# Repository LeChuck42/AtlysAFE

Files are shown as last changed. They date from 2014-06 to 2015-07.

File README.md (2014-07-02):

AtlysAFE
========

The goal of this project is an analog frontend for the [Digilent Atlys](http://www.digilentinc.com/Products/Detail.cfm?NavPath=2,400,836&Prod=ATLYS) FPGA Development Board.
The board consists of a XILINX Spartan 6 FPGA and several peripherals. Other expansion modules
can be connected via the VHDCI connector.

The analog frontend will use this expansion port to connect two high speed ADCs and two high speed
DACs to the FPGA. My plan it to use this board as a base for a [Software Defined Radio](http://en.wikipedia.org/wiki/Software-defined_radio).

Layout
------
For most of the ICs free samples are available and the footprints are designed in a way that allows the board to be hand-soldered (using QFN with long pads and no BGA).

I chose a 6 layer layout because the impedance controlled traces need a small distance to their reference plane. In small quantities it seems to be cheaper to use 6 layers instead of defining a low prepreg thickness for a 4 layer design.

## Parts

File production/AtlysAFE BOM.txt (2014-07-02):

Comment	Description	Designator	Footprint	LibRef	Quantity

"0603_MUX4"	""	"R103, R104, R105, R106"	"0603_MUX4"	"0603_MUX4"	"4"
"600R@100Mhz"	""	"L300, L600, L601"	"0805"	"L"	"3"
"93LC56C"	"2K Microwire Compatible Serial EEPROM"	"IC601"	"MSOP8"	"93LC56C"	"1"
"LMK00304"	"3-GHz 4-Output Differential Clock Buffer/Level Translator"	"IC701"	"WQFN32_LONG"	"LMK00304"	"1"
"GPIO"	"16POLPF"	"P3"	"16POL_PF2"	"16POLPF"	"1"
"TPS7A4700"	"36V, 1A, Low Noise, RF LDO Voltage Regulator"	"IC500, IC502"	"VQFN20_LONG"	"TPS7A4700"	"2"
"VHDCI-68"	"68-Pin VHDCI Connector"	"P1"	"VHDCI-68_M"	"MALE_VHDCI-68"	"1"
"USB TYP MICRO-B"	"10118194-0001LF"	"P2"	"USB_MICRO_B_SMD_4DIP"	"USB TYP MICRO-B"	"1"
"120R@100Mhz"	"742792023"	"L500, L502, L503, L504, L506, L507"	"0805"	"L"	"6"
"10.00MHz"	"AST3TQ-10.00MHz-1"	"XO700"	"AST3TQ"	"OSZILLATOR_4P SMD"	"1"
"100n"	"C"	"C101, C102, C103, C104, C106, C107, C108, C110, C111, C114, C115, C120, C155, C200, C201, C204, C208, C209, C212, C300, C301, C302, C303, C304, C305, C306, C307, C308, C309, C310, C311, C312, C313, C314, C315, C316, C317, C318, C400, C401, C402, C403, C404, C405, C406, C407, C408, C409, C410, C501, C507, C516, C523, C601, C602, C603, C605, C606, C607, C608, C610, C612, C615, C747"	"0603 SMALL OUTLINE"	"C"	"64"
"100n"	"C"	"C725, C728, C740, C741, C743, C744, C745, C748"	"0402"	"C"	"8"
"100p"	"C"	"C521"	"0603 SMALL OUTLINE"	"C"	"1"
"10n"	"C"	"C511, C520, C737"	"0603 SMALL OUTLINE"	"C"	"3"
"10n"	"C"	"C702, C703, C704, C706, C707, C712, C713, C714, C716, C719, C720, C726, C727, C729"	"0402"	"C"	"14"
"10u"	"C"	"C202, C211, C733, C734"	"0805 SMALL OUTLINE"	"C"	"4"
"18pF"	"C"	"C613, C614"	"0603 SMALL OUTLINE"	"C"	"2"
"1n"	"C"	"C738, C739"	"0603 SMALL OUTLINE"	"C"	"2"
"1n2"	"C"	"C513"	"0603 SMALL OUTLINE"	"C"	"1"
"1nF / 200V"	"C"	"C1, C5"	"1206"	"C"	"2"
"1u"	"C"	"C100, C105, C500, C504, C510, C519, C525, C600, C604, C700, C705, C708, C709, C710, C711, C715, C717, C718, C721, C722, C723, C724, C730, C731, C732, C735, C742, C749"	"0603 SMALL OUTLINE"	"C"	"28"
"22u"	"C"	"C2, C3, C503, C505, C506, C514, C515, C526"	"1206"	"C"	"8"
"270n"	"C"	"C736"	"0603 SMALL OUTLINE"	"C"	"1"
"2n7"	"C"	"C522"	"0603 SMALL OUTLINE"	"C"	"1"
"2nF"	"C"	"C109"	"0603 SMALL OUTLINE"	"C"	"1"
"2u2"	"C"	"C746"	"0603 SMALL OUTLINE"	"C"	"1"
"47u"	"C"	"C502, C508, C509, C517, C518, C524"	"1206"	"C"	"6"
"4u7F"	"C"	"C609, C611"	"0603 SMALL OUTLINE"	"C"	"2"
"C"	"C"	"C118, C119"	"0603 SMALL OUTLINE"	"C"	"2"
"NU"	"C"	"C512"	"0603 SMALL OUTLINE"	"C"	"1"
"TBD"	"C, R"	"C112, C113, C116, C117, C205, C206, C207, C213, C214, C215, R110, R111, R118, R120, R209, R224, R310, R311, R312, R313, R314, R315, R316, R317, R318, R319, R320, R321"	"0603 SMALL OUTLINE"	"C, R"	"28"
"ADP2114"	"Configurable DC/DC Sync. Buck, Dual 2A / Single 4A"	"IC501"	"LFCSP32_LONG"	"ADP2114"	"1"
"4u7"	"DR74-XXX-R"	"L501, L505"	"DR74"	"L"	"2"
"FT2232HL"	"DUAL HIGH SPEED USB TO MULTIPURPOSE UART/FIFO IC"	"IC600"	"64QFN"	"FT2232HL"	"1"
"DAC3283"	"Dual-Channel,  16-Bit,  800  MSPS,  Digital-to-Analog  Converter  (DAC)"	"IC300"	"VQFN48_LONG"	"DAC3283"	"1"
"ADS6245"	"DUAL CHANNEL, 14-BIT, 125/105/80/65 MSPS ADC WITH SERIAL LVDS OUTPUTS"	"IC100"	"VQFN48_LONG"	"ADS6245_2WIRE"	"1"
"100µ"	"EEH-ZA1E101XP"	"C4, C701"	"SMD_ELKO_6.3"	"ELCO"	"2"
"CDCE62005"	"Five/Ten Output Clock Generator/Jitter Cleaner With Integrated Dual VCOs"	"IC700"	"48VQFN"	"CDCE62005"	"1"
"120R"	"L"	"FB700, FB703, FB704, FB705, FB706, FB707, FB709, FB710, FB711"	"0805 SMALL OUTLINE"	"L"	"9"
"1k"	"L"	"FB701, FB702, FB708"	"0805 SMALL OUTLINE"	"L"	"3"
"Ferrite"	"L"	"L700"	"0805"	"L"	"1"
"LCMXO2-2000HC-4TG100C"	"Lattice MachXO2"	"IC400"	"TQFP100"	"LCMXO2-2000HC-4TG100C"	"1"
"MCX"	"MCX Connector"	"X1, X2, X3, X4, X5, X6, X7, X8, X9, X10, X11, X12, X13, X14"	"MCX_TH"	"MCX"	"14"
"(0R)"	"R"	"R207, R222, R717, R719, R726"	"0603 SMALL OUTLINE"	"R"	"5"
"(0R)"	"R"	"R706, R707, R708, R714"	"0402"	"R"	"4"
"(100R)"	"R"	"R720, R725"	"0402"	"R"	"2"
"(500)"	"R"	"R202, R213, R217, R228"	"0603 SMALL OUTLINE"	"R"	"4"
"(50R)"	"R"	"R709, R729"	"0402"	"R"	"2"
"0R"	"R"	"R107, R201, R203, R216, R218, R300, R301, R500, R600, R601, R602, R603, R700, R716, R718"	"0603 SMALL OUTLINE"	"R"	"15"
"0R"	"R"	"R2"	"1206"	"R"	"1"
"0R"	"R"	"R407, R408, R710, R711, R712, R713, R715, R722, R724, R727, R728"	"0402"	"R"	"11"
"100k"	"R"	"R505"	"0603 SMALL OUTLINE"	"R"	"1"
"100R"	"R"	"R303, R306"	"0603 SMALL OUTLINE"	"R"	"2"
"100R"	"R"	"R400, R401, R402"	"0402"	"R"	"3"
"10k"	"R"	"R309, R608, R609, R610, R611, R704, R705"	"0603 SMALL OUTLINE"	"R"	"7"
"10R"	"R"	"R501"	"0603 SMALL OUTLINE"	"R"	"1"
"11k5"	"R"	"R511"	"0603 SMALL OUTLINE"	"R"	"1"
"12k"	"R"	"R612"	"0603 SMALL OUTLINE"	"R"	"1"
"150R"	"R"	"R304, R305, R307, R308"	"0603 SMALL OUTLINE"	"R"	"4"
"15k"	"R"	"R510"	"0603 SMALL OUTLINE"	"R"	"1"
"169R"	"R"	"R204, R208, R219, R223"	"0603 SMALL OUTLINE"	"R"	"4"
"1k"	"R"	"R604, R701, R721, R730"	"0603 SMALL OUTLINE"	"R"	"4"
"1k1"	"R"	"R703"	"0603 SMALL OUTLINE"	"R"	"1"
"1M"	"R"	"R1"	"1206"	"R"	"1"
"220R"	"R"	"R605, R606"	"0603 SMALL OUTLINE"	"R"	"2"
"22k"	"R"	"R101, R508"	"0603 SMALL OUTLINE"	"R"	"2"
"2k2"	"R"	"R613"	"0603 SMALL OUTLINE"	"R"	"1"
"330R"	"R"	"R702"	"0603 SMALL OUTLINE"	"R"	"1"
"33k"	"R"	"R100, R102"	"0603 SMALL OUTLINE"	"R"	"2"
"348R"	"R"	"R200, R214, R215, R229"	"0603 SMALL OUTLINE"	"R"	"4"
"470R"	"R"	"R403, R404, R405, R406"	"0603 SMALL OUTLINE"	"R"	"4"
"47k"	"R"	"R108, R109, R212, R227, R506, R507, R509"	"0603 SMALL OUTLINE"	"R"	"7"
"49R9"	"R"	"R210, R211, R225, R226"	"0603 SMALL OUTLINE"	"R"	"4"
"4k7"	"R"	"R503, R607"	"0603 SMALL OUTLINE"	"R"	"2"
"50R"	"R"	"R112, R113, R114, R115"	"0603 SMALL OUTLINE"	"R"	"4"
"56k"	"R"	"R504"	"0603 SMALL OUTLINE"	"R"	"1"
"5R"	"R"	"R116, R117, R119, R121"	"0603 SMALL OUTLINE"	"R"	"4"
"8k2"	"R"	"R502"	"0603 SMALL OUTLINE"	"R"	"1"
"960R"	"R"	"R302"	"0603 SMALL OUTLINE"	"R"	"1"
"DNP"	"R"	"R723"	"0603 SMALL OUTLINE"	"R"	"1"
"R"	"R"	"R122, R123, R124, R125"	"0603 SMALL OUTLINE"	"R"	"4"
"SMD_MARKER"	"SMD MARKER"	"M1, M2, M3"	"SMDMark100 - nopaste"	"SMD_MARKER"	"3"
"2PPHOE"	"Steckbare Scharubklemme 2pol."	"P4"	"2PPHOE"	"2PPHOE"	"1"
"TEST PAD"	"Test Pad"	"TP500"	"TEST_PAD_50"	"TEST PAD"	"1"
"TESTPOINT"	"TESTPOINT"	"TP700"	"TEST_PAD_50"	"TESTPOINT"	"1"
"THS4509"	"WIDEBAND, LOW-NOISE, LOW-DISTORTION, FULLY-DIFFERENTIAL AMPLIFIER"	"IC200, IC201"	"QFN16_LONG"	"THS4509"	"2"
"RED"	"WURTH 150060SS75000"	"D403"	"LED SMD 0603"	"LED SMD"	"1"
"GRN"	"WURTH 150060VS75000"	"D400, D401, D402, D700"	"LED SMD 0603"	"LED SMD"	"4"
"RX LED"	"WURTH 150060VS75000"	"D600"	"LED SMD 0603"	"LED SMD"	"1"
"TX LED"	"WURTH 150060VS75000"	"D601"	"LED SMD 0603"	"LED SMD"	"1"
"12MHz"	"XX MHz"	"Q600"	"SMD_XTAL_5x3.2"	"CRYSTAL"	"1"
"TBD"	"XX MHz"	"Q700"	"XTAL_SMD_60_35"	"CRYSTAL"	"1"

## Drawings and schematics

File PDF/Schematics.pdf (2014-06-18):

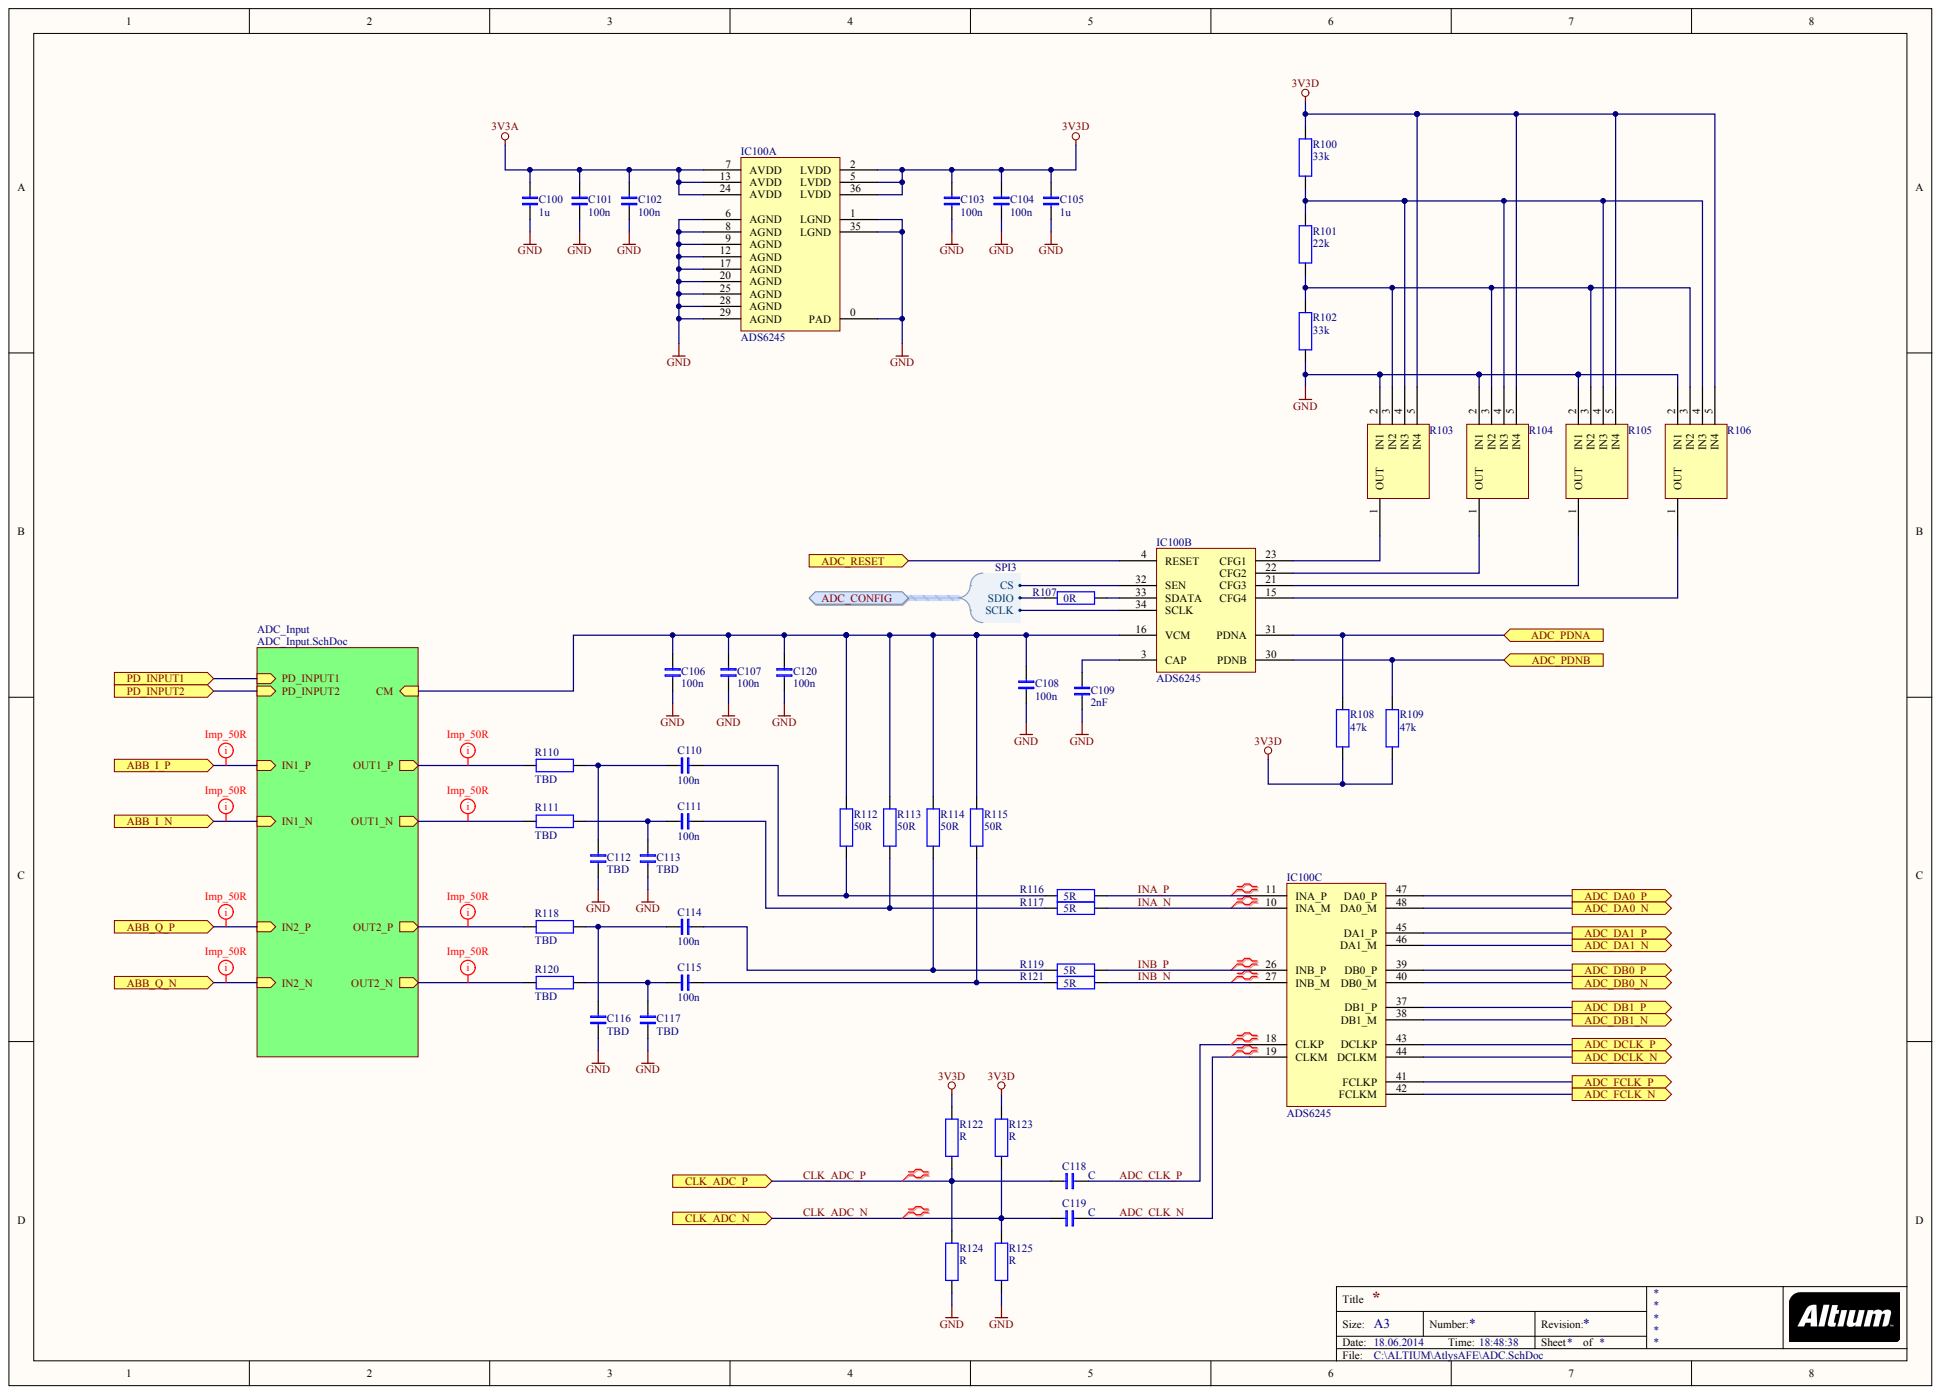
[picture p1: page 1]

AGND 9
AGND 12
AGND 17
AGND 20
AGND 25

AGND 29

Title | *

Size: A3 | Number: | Revision:
Date: 18.06.2014 Time: 18:48:38 | | Sheet * of *

C:\ALTIUM\AtlysAFE\ADC.SchDoc

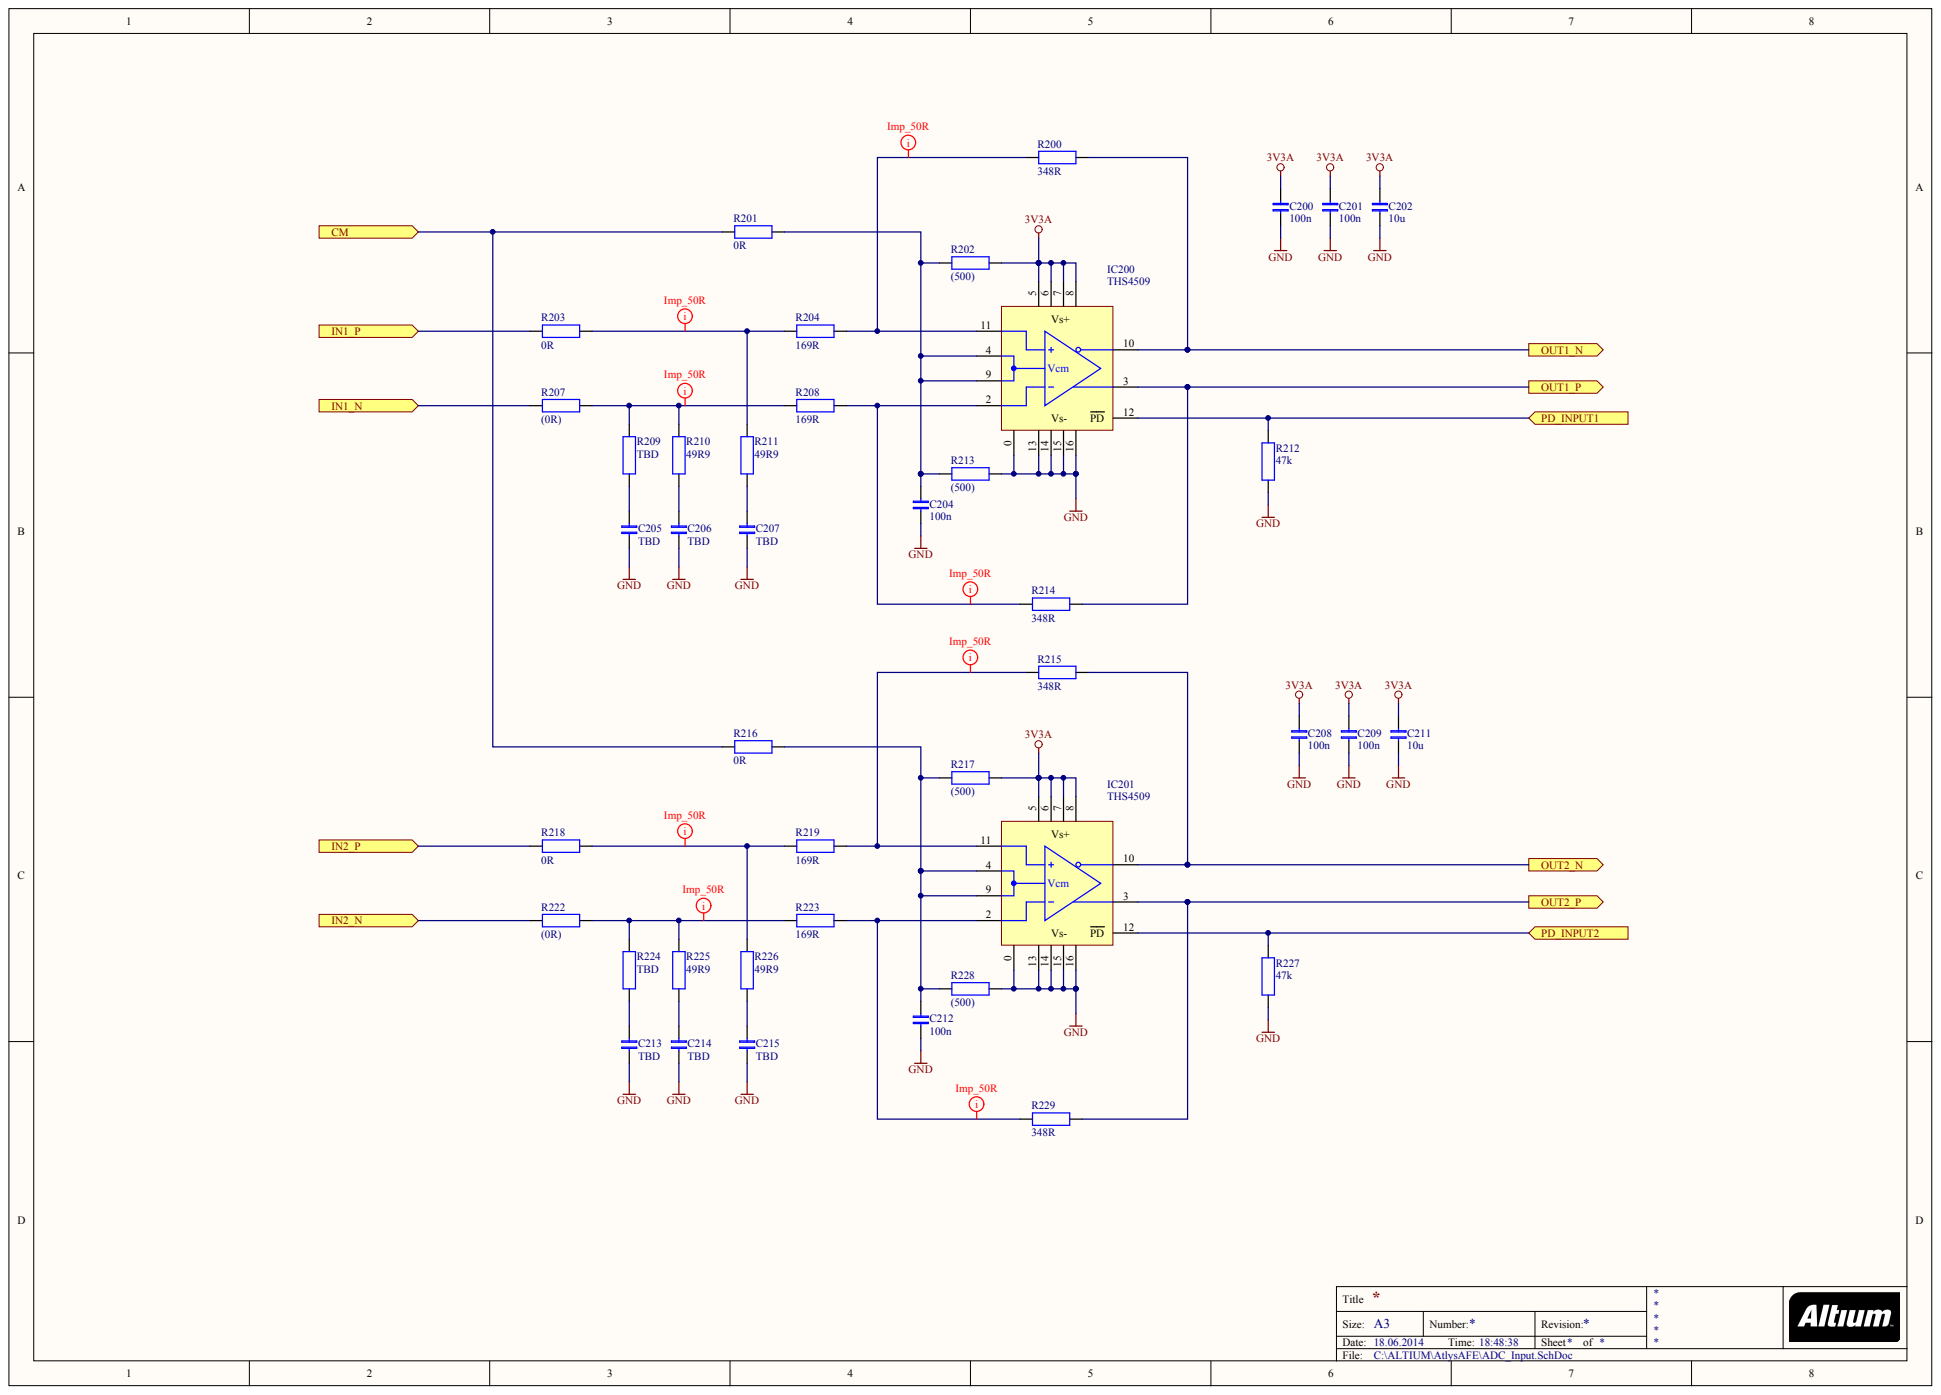
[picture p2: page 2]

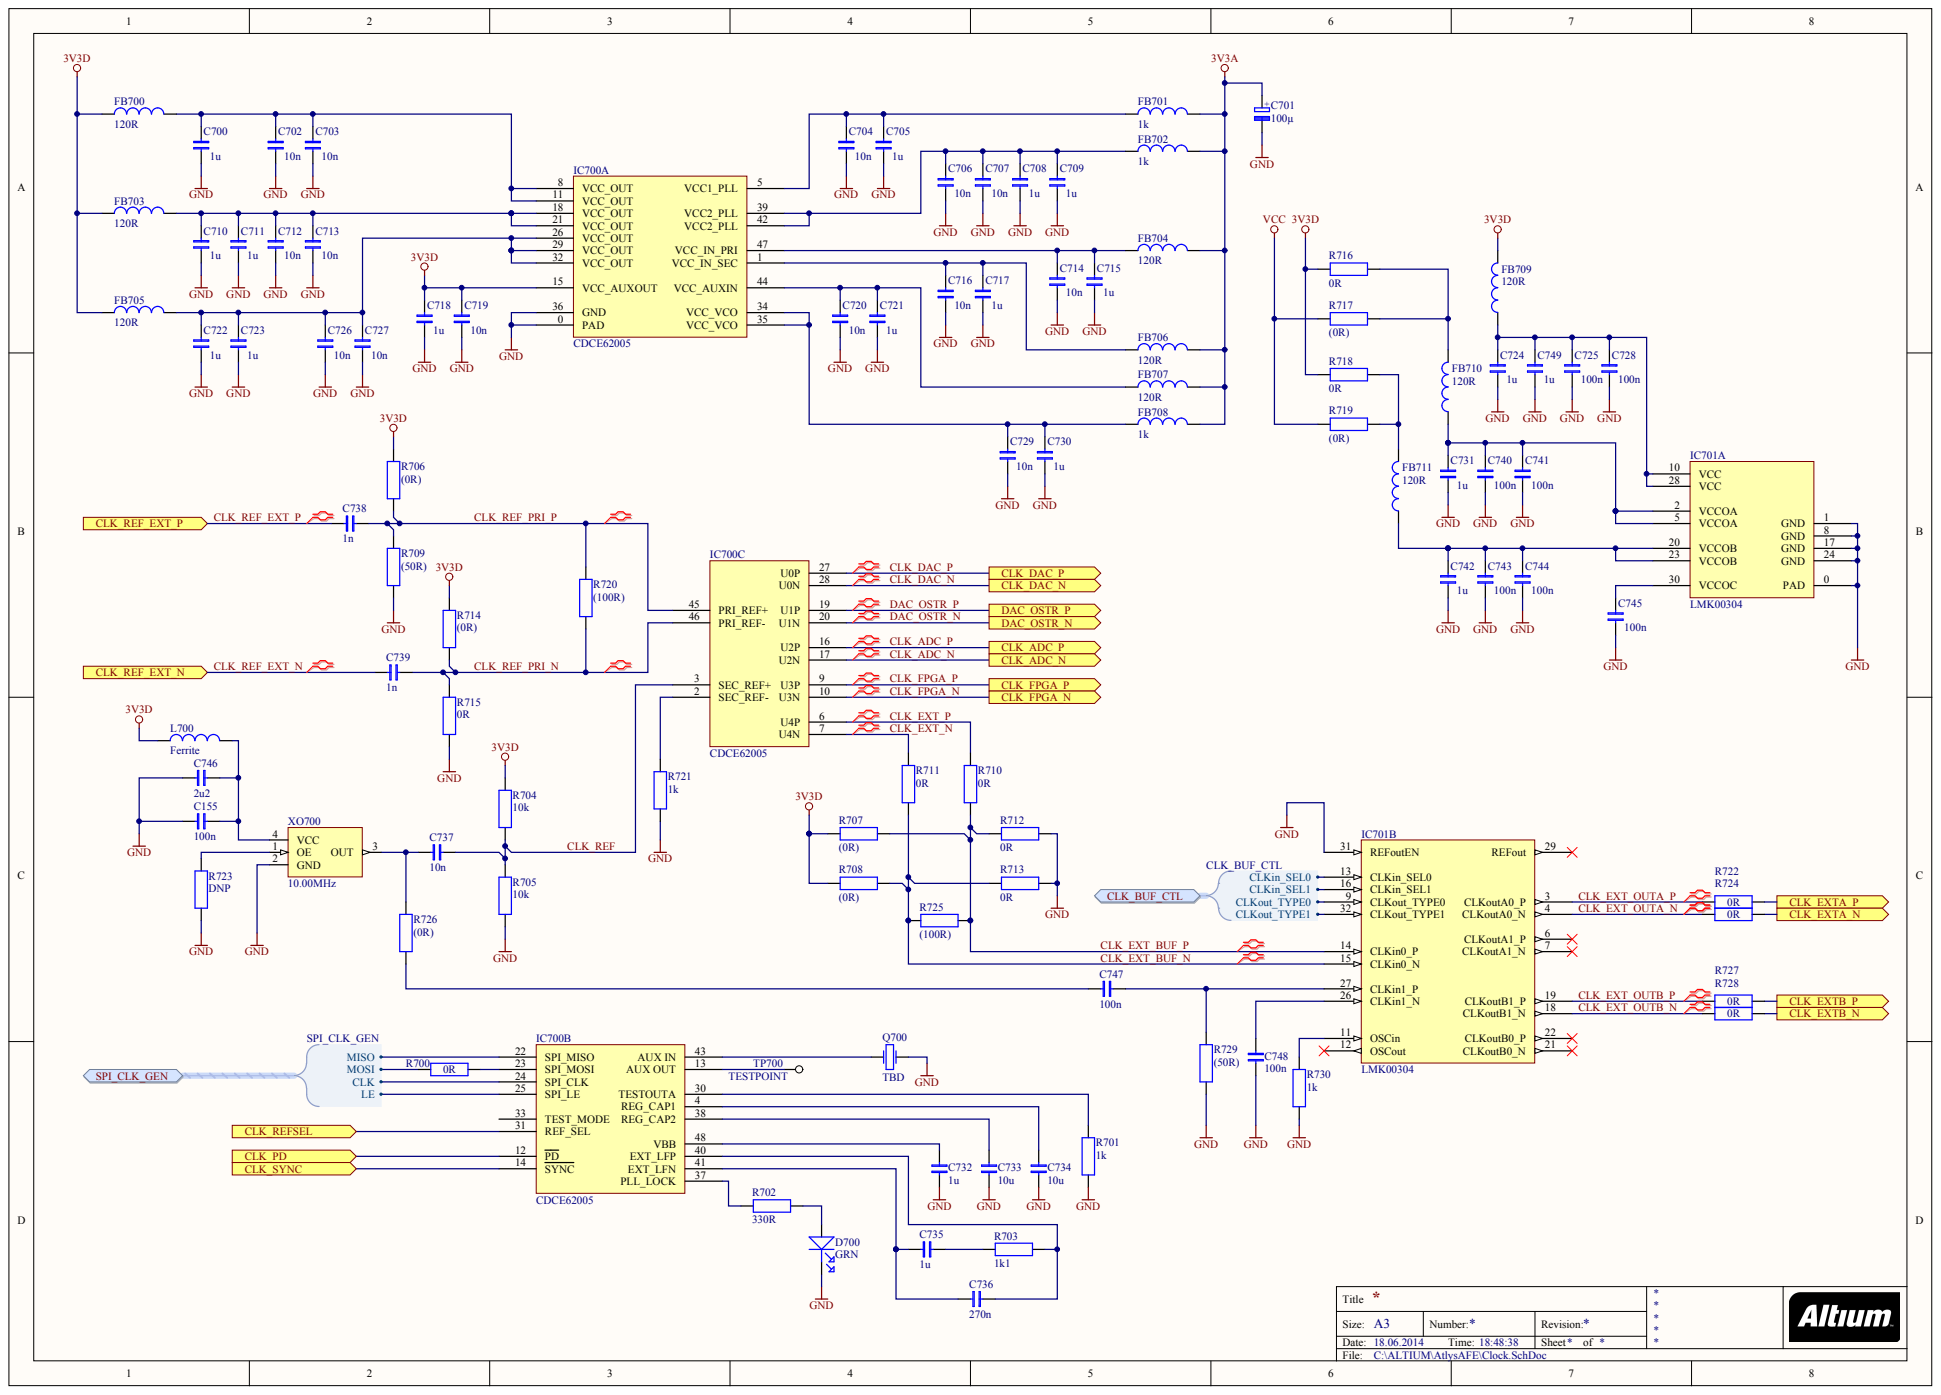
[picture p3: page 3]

PAD 0

GND | GND

CLKin1_N 26 CLKin1_P 27

C:\ALTIUM\AtlysAFE\Clock.SchDoc

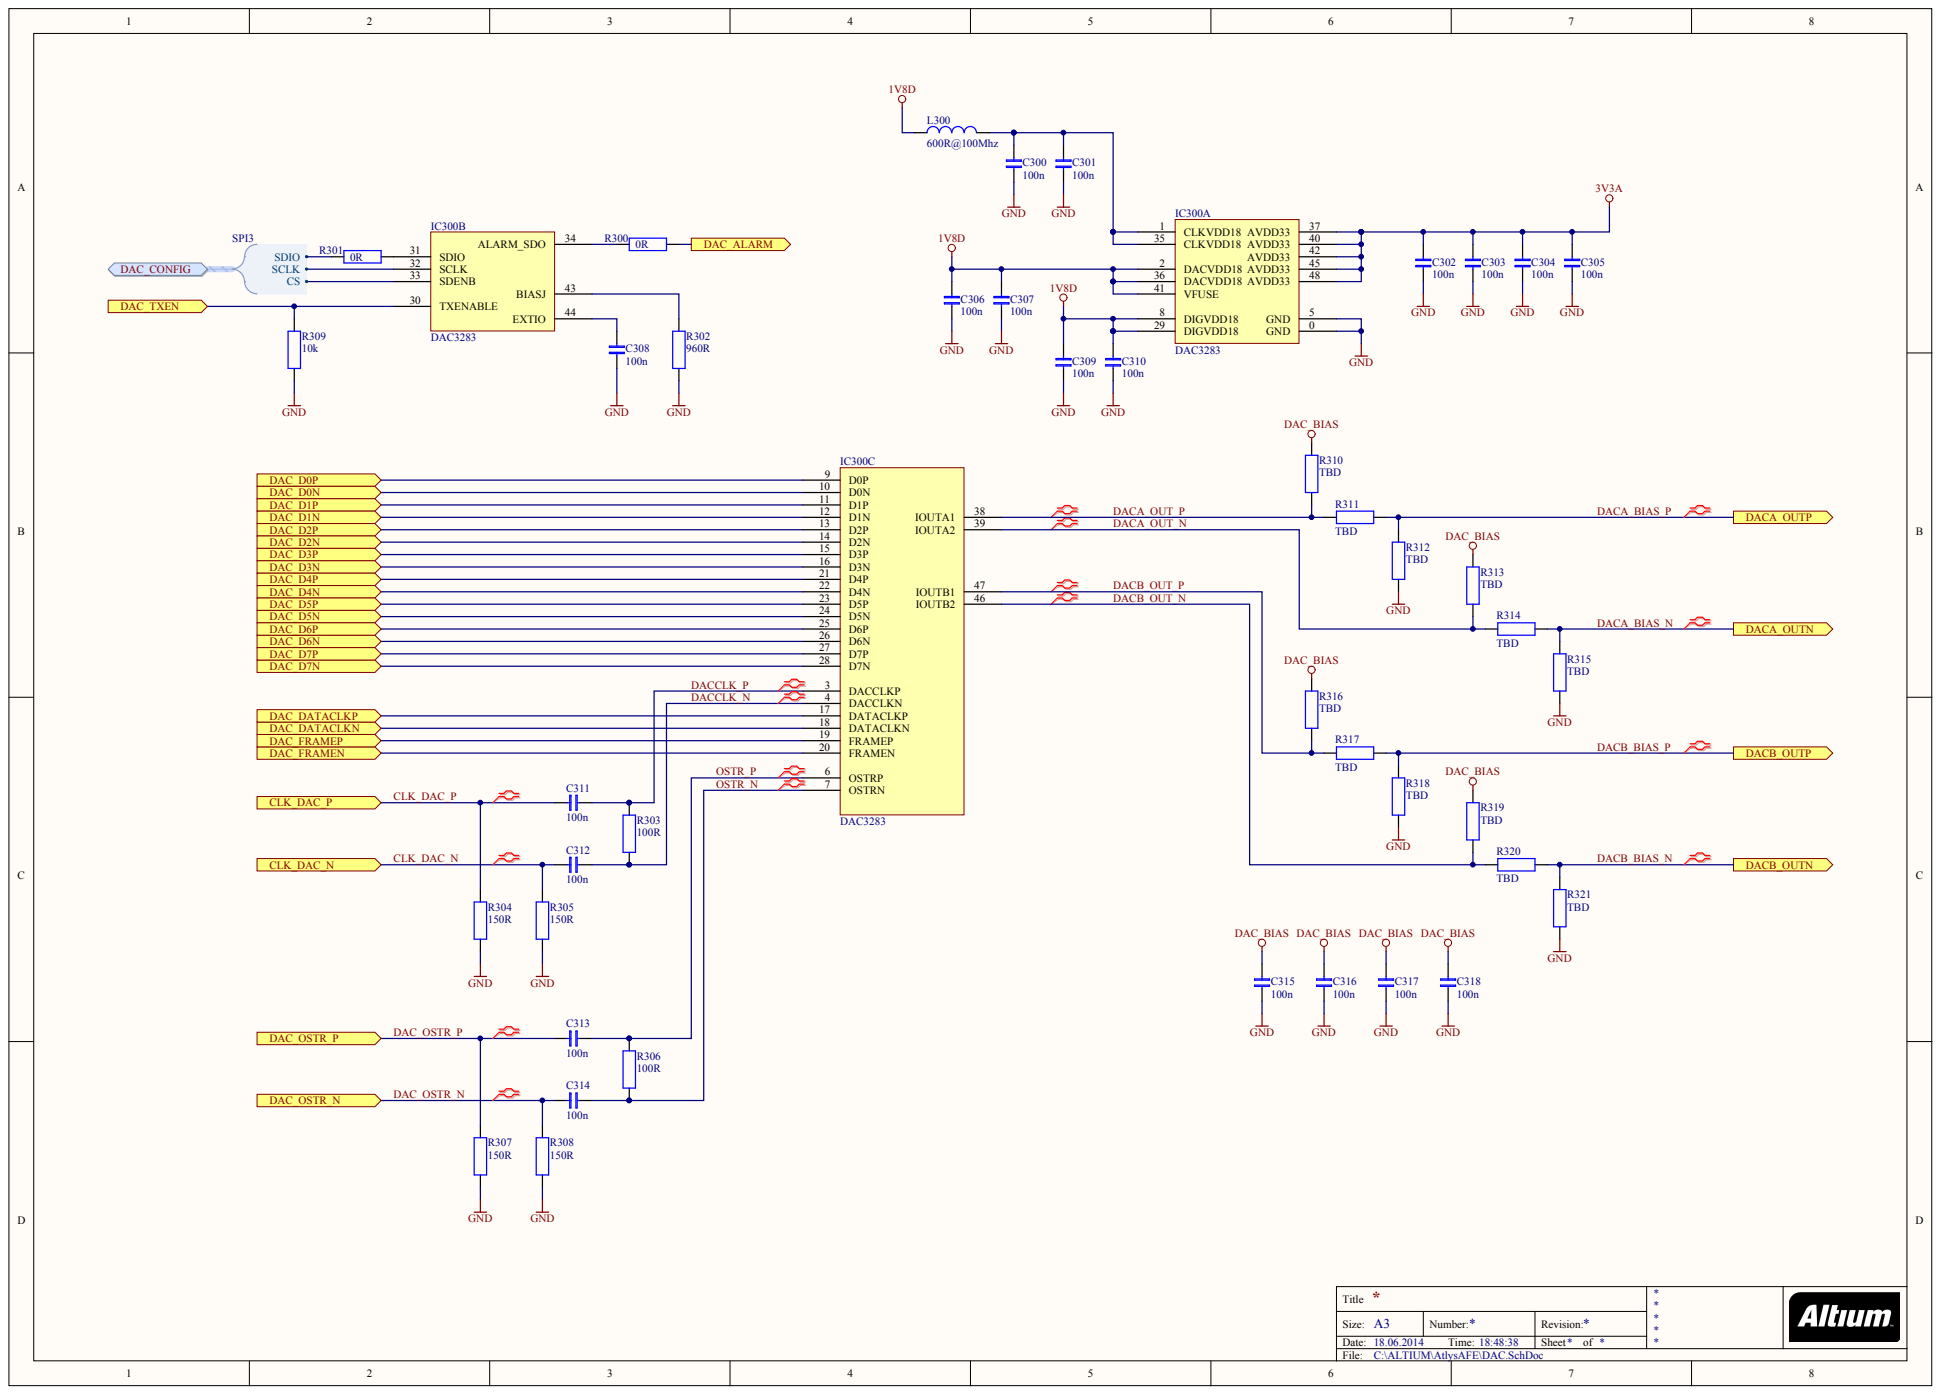
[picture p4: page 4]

D5P 23 | DACB_OUT_N
D5N 24 | | GND

D6N 26 | DAC_BIAS | R317

DACCLK_N | DACCLKN 4

DATACLKP 17
DATACLKN 18
FRAMEP 19
FRAMEN 20

OSTR_P | OSTRP 6
OSTR_N | OSTRN 7

C:\ALTIUM\AtlysAFE\DAC.SchDoc

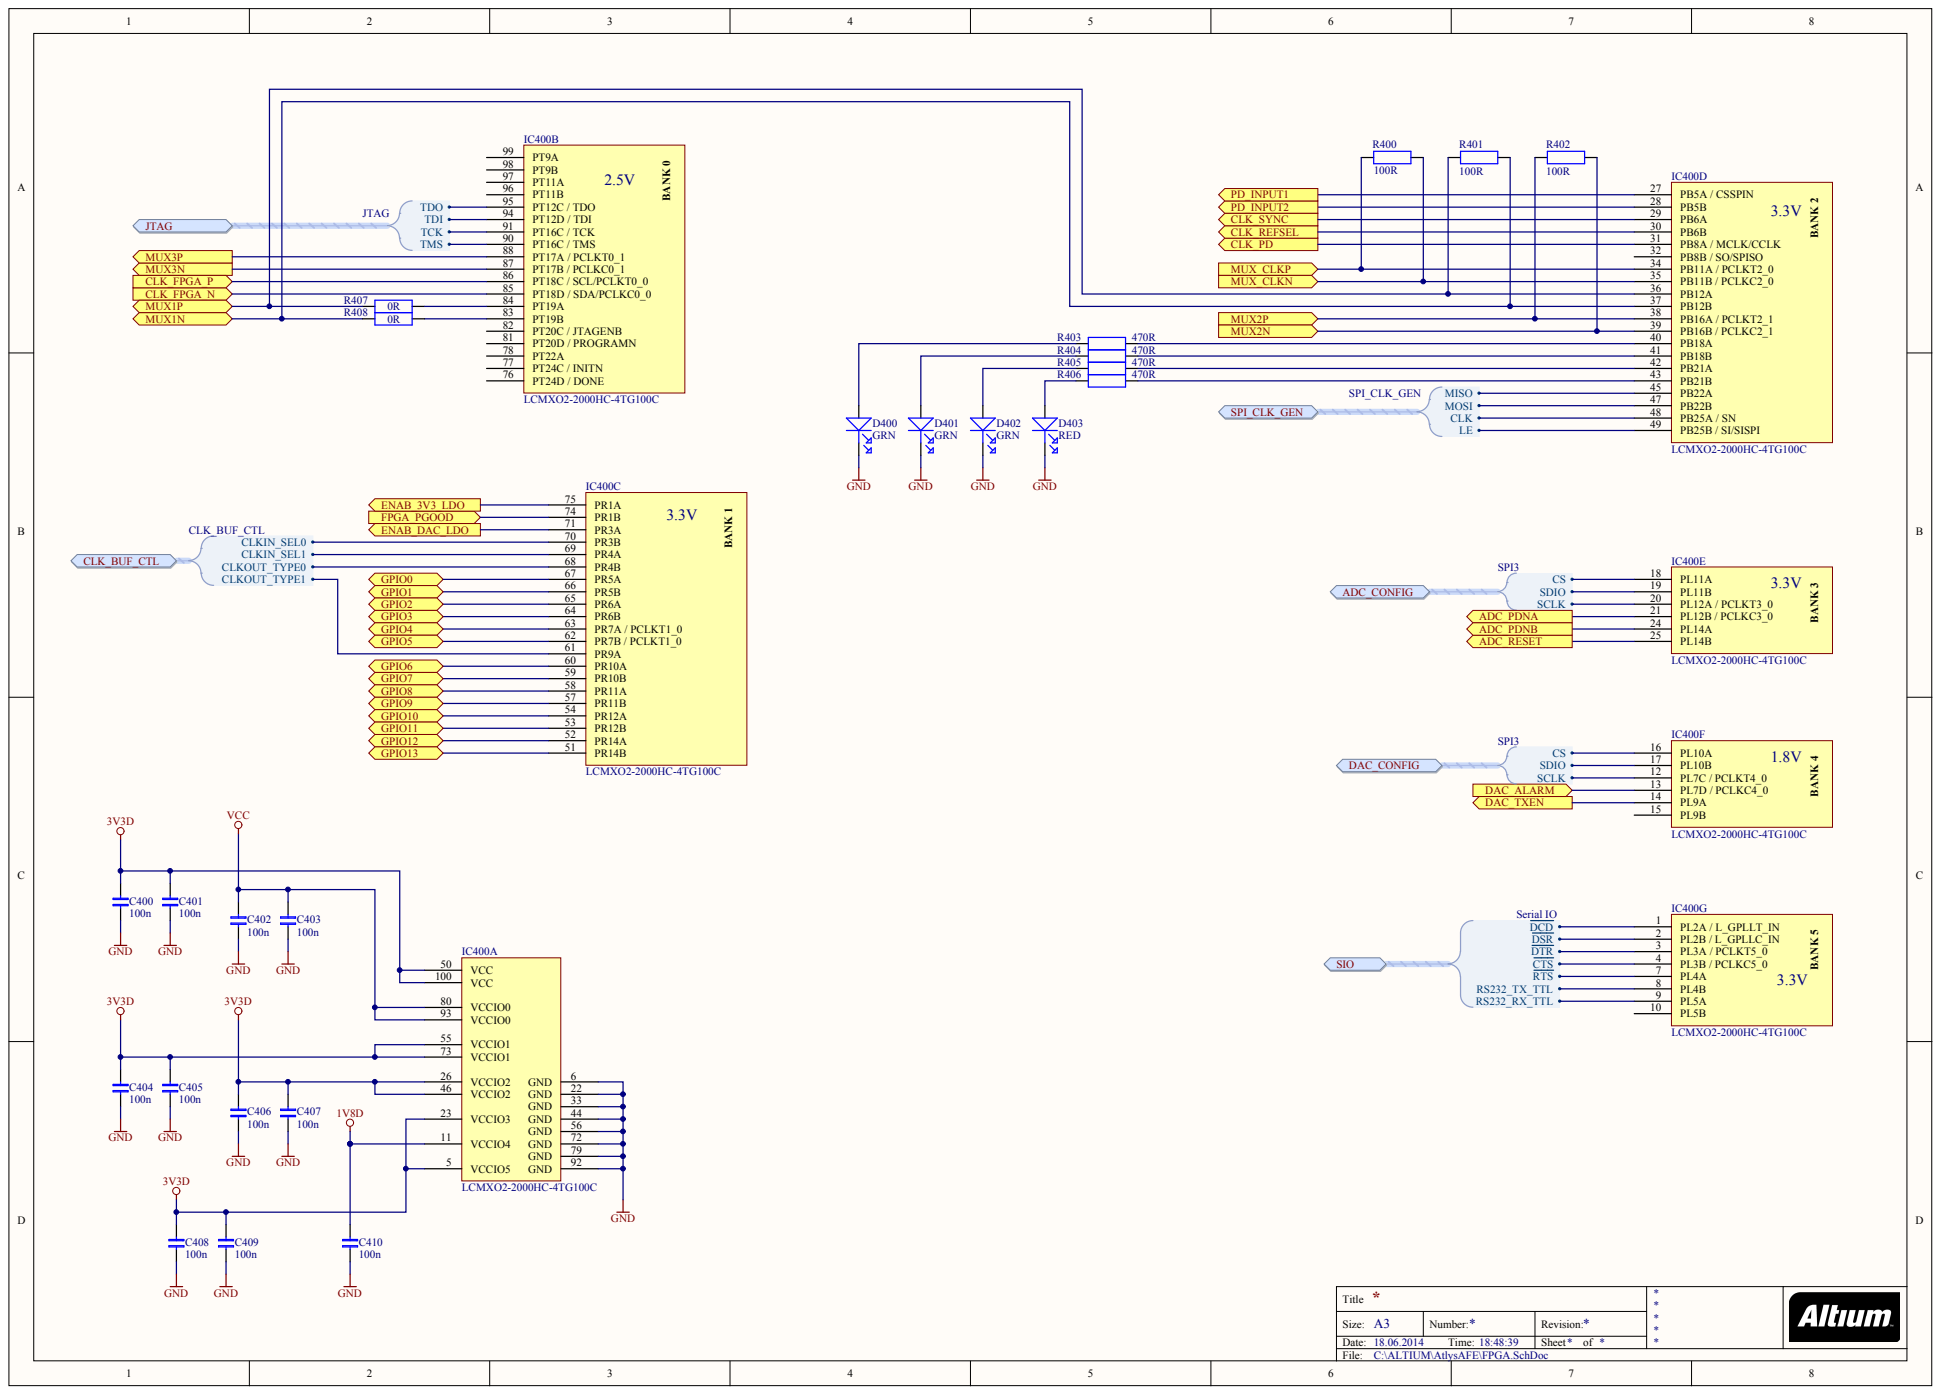
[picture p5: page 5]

R404 | 470R | PB18B 41
R405 | 470R | PB21A 42
R406 | 470R | PB21B 43

C400 GND | C401

C402 GND | C403

VCCIO0 80

C:\ALTIUM\AtlysAFE\FPGA.SchDoc

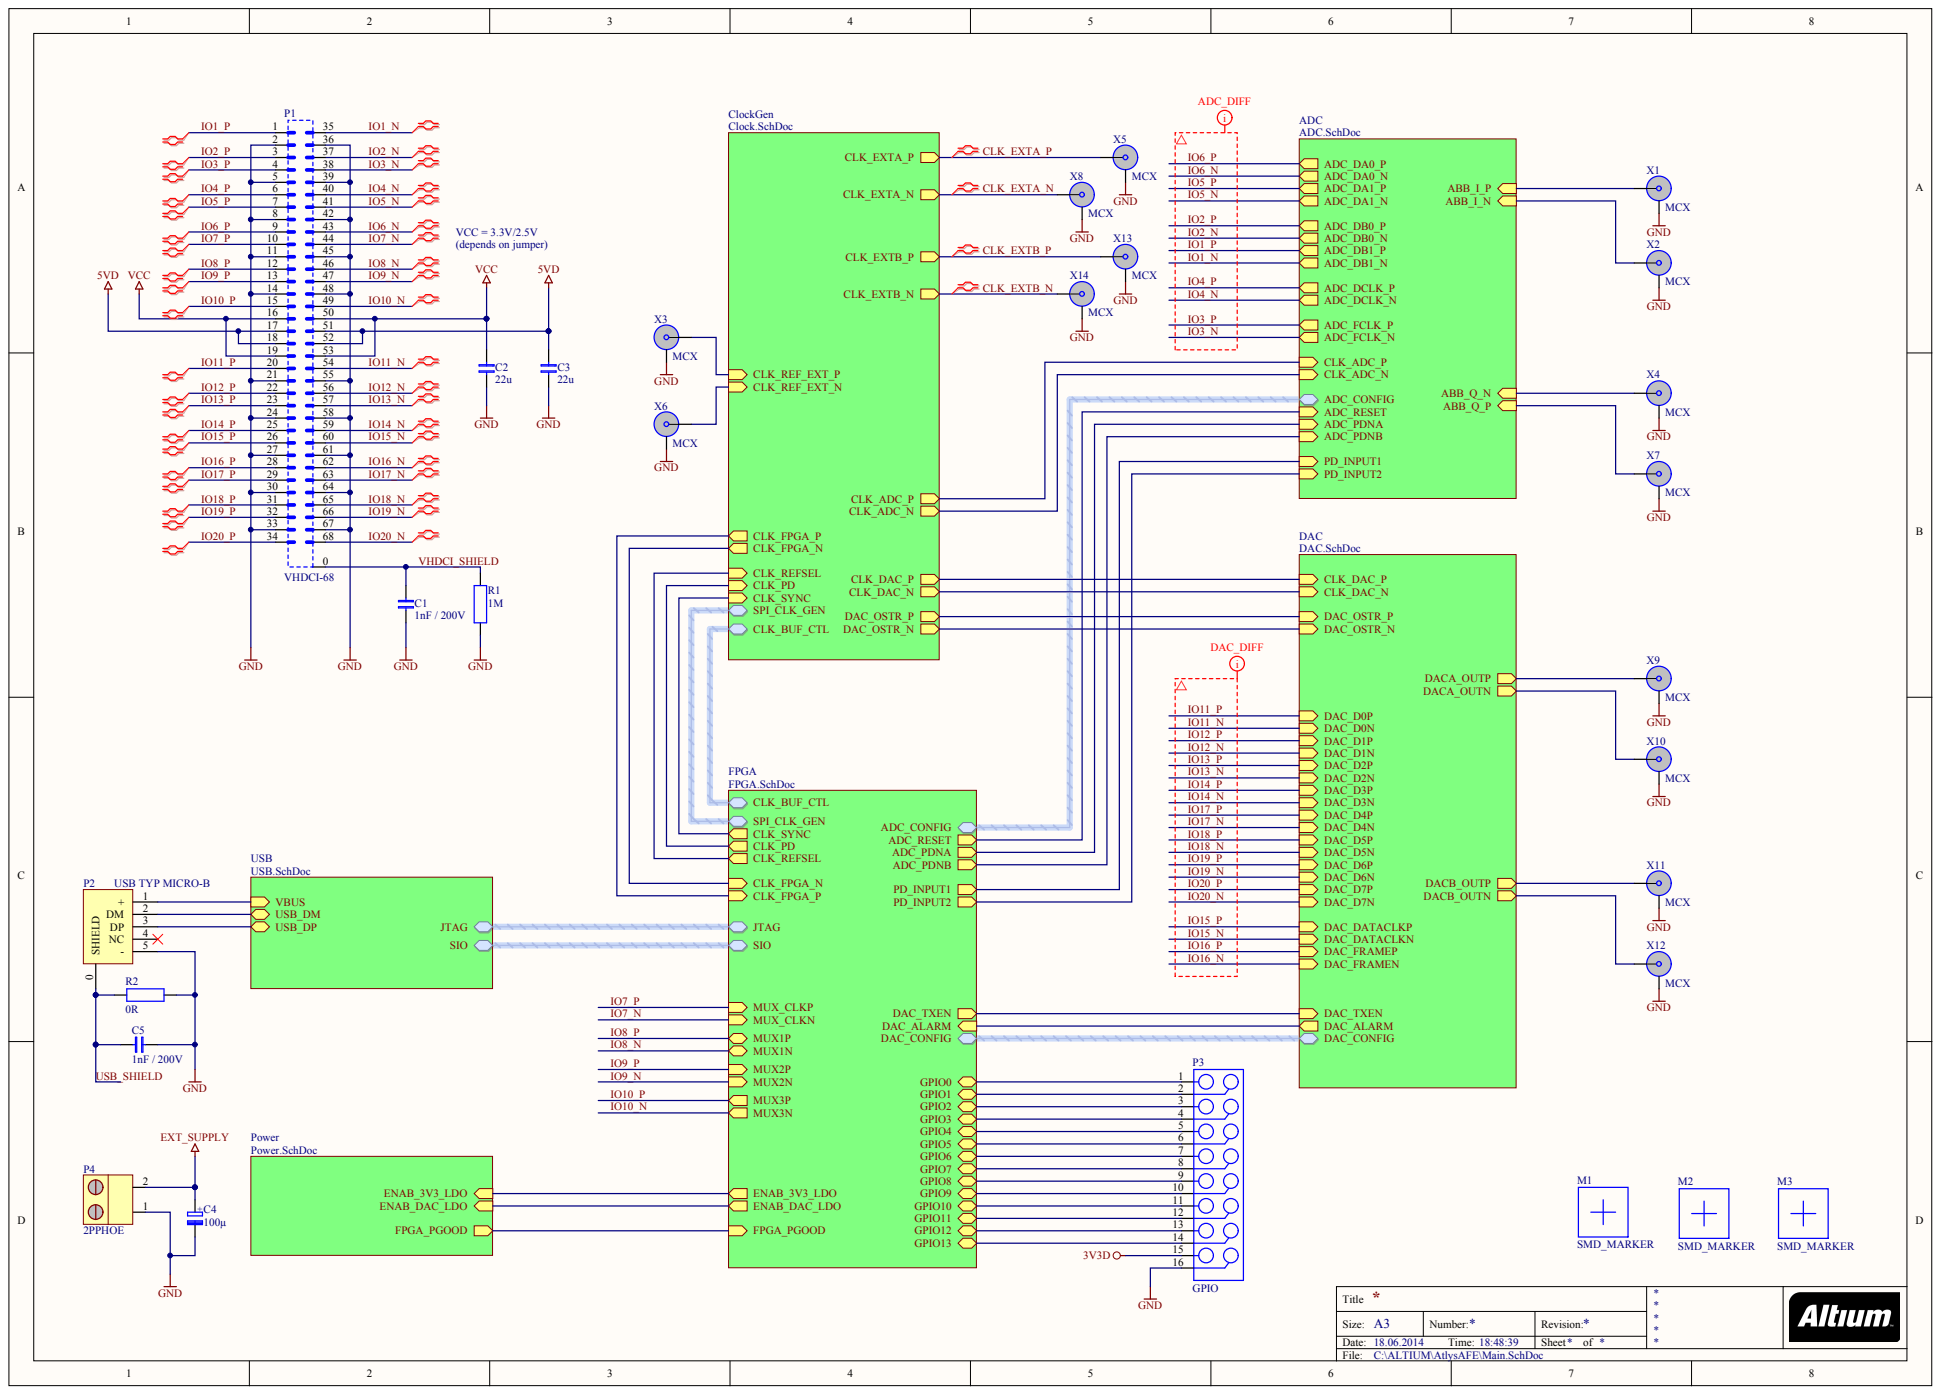
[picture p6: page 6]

17 | | | 51
18 | | | 52 | IO17_N IO18_N IO19_N
19 | | | 53
20 21 | | | 54 55

IO18_N
IO19_P
IO19_N IO20_P

SHIELD 0 P2 USB TYP MICRO-B

C:\ALTIUM\AtlysAFE\Main.SchDoc

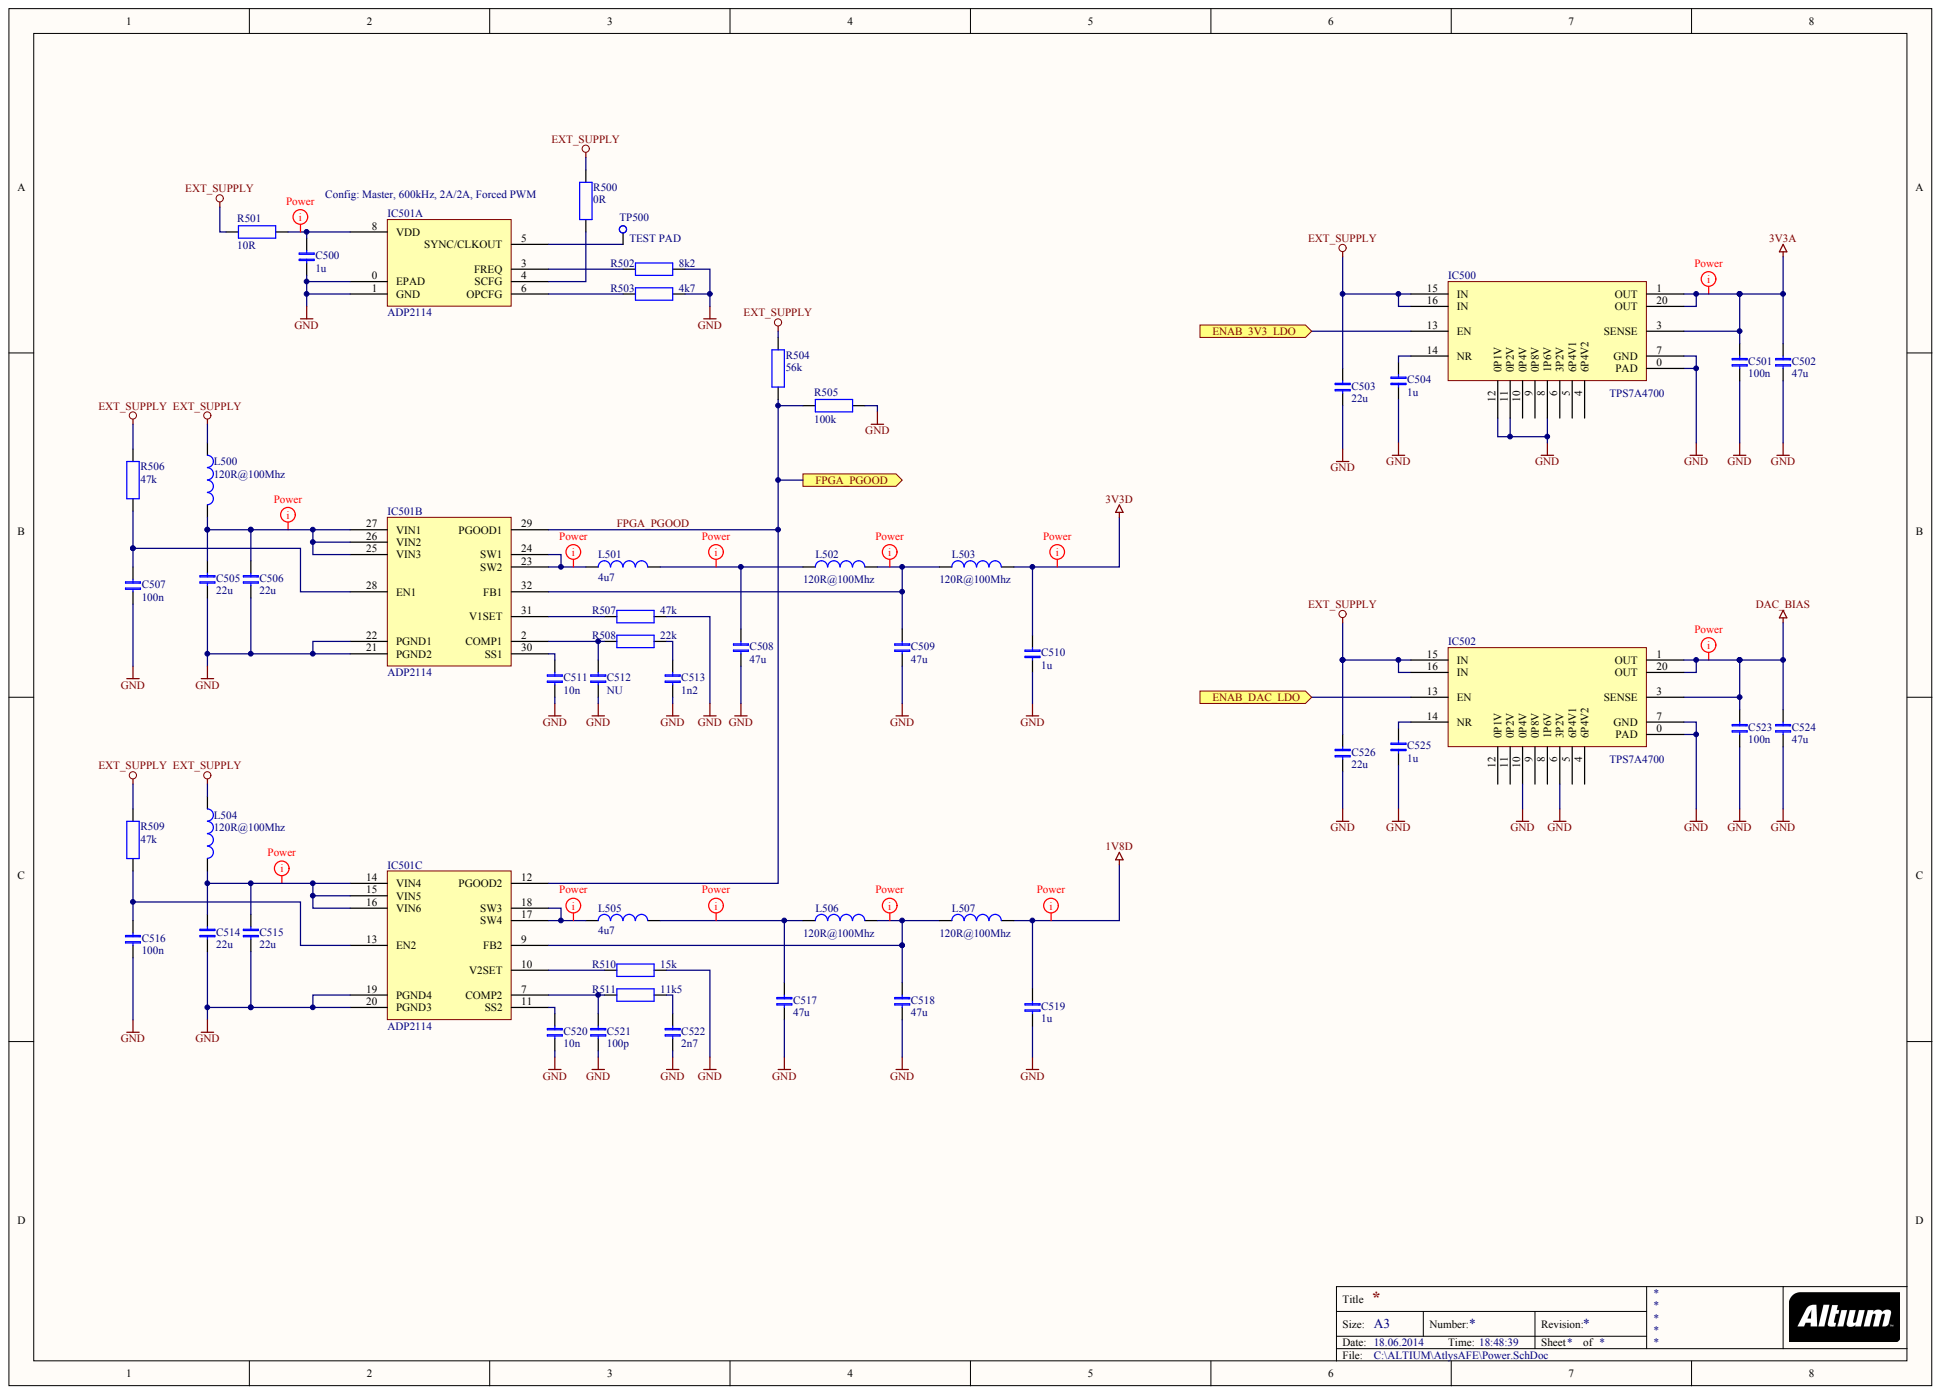
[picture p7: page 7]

VIN5 15 | Power

PGND4 19

C:\ALTIUM\AtlysAFE\Power.SchDoc

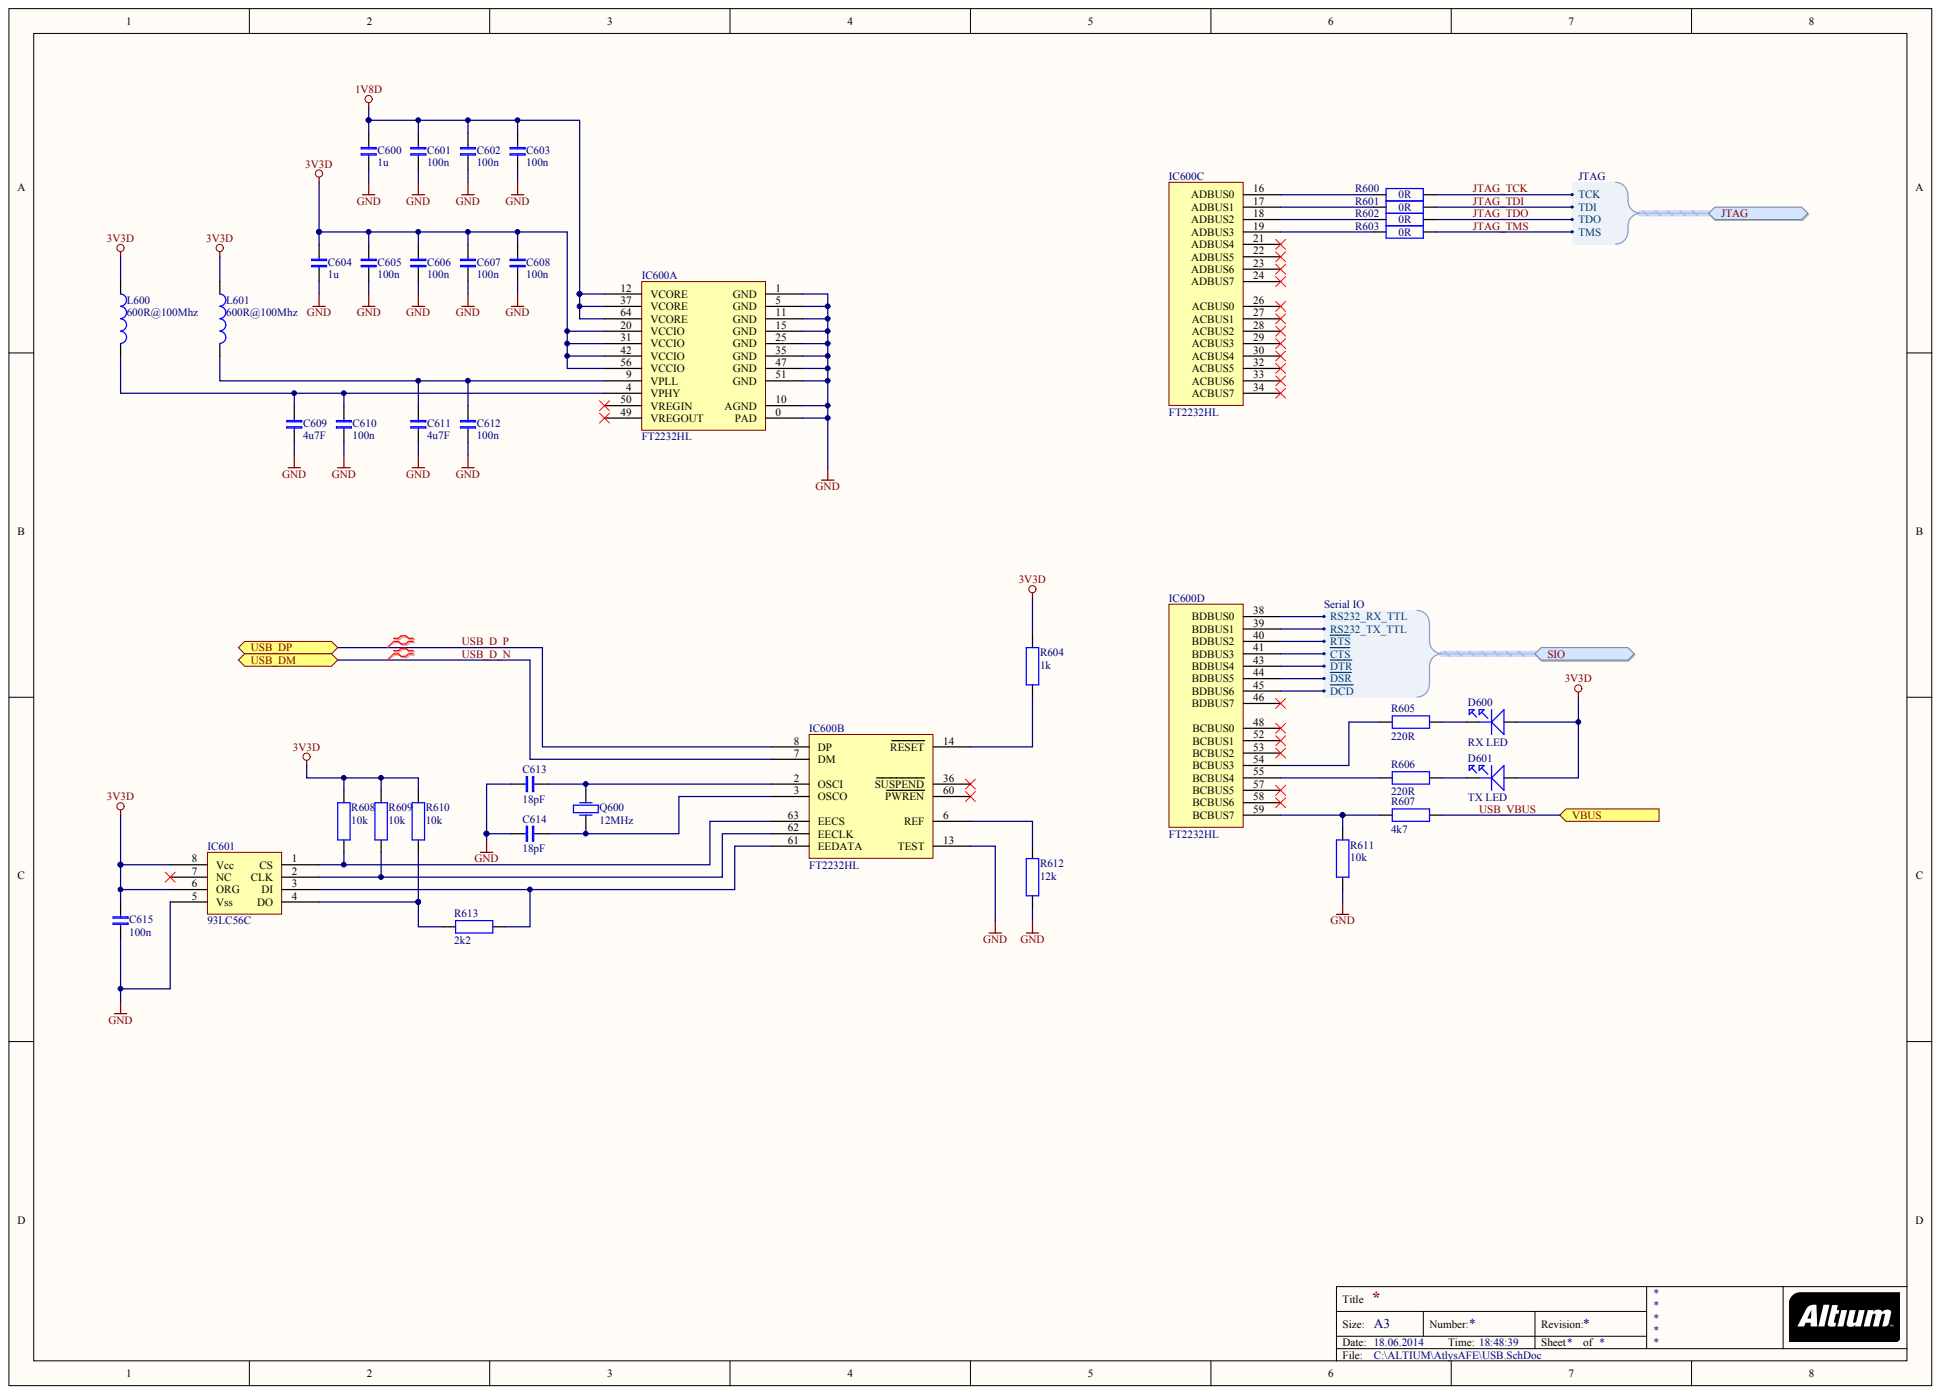
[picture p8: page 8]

OSCI 2

EECS 63
EECLK 62
EEDATA 61

18pF GND

C:\ALTIUM\AtlysAFE\USB.SchDoc

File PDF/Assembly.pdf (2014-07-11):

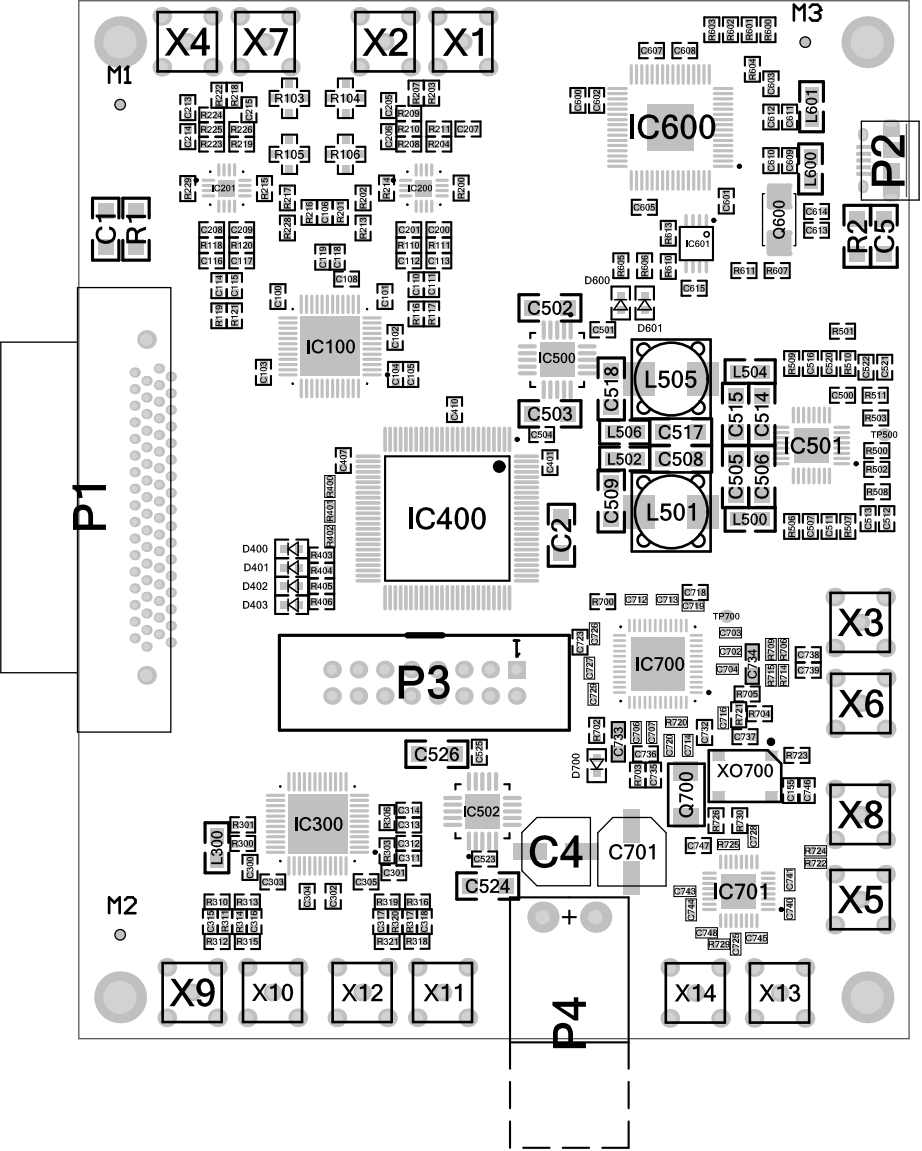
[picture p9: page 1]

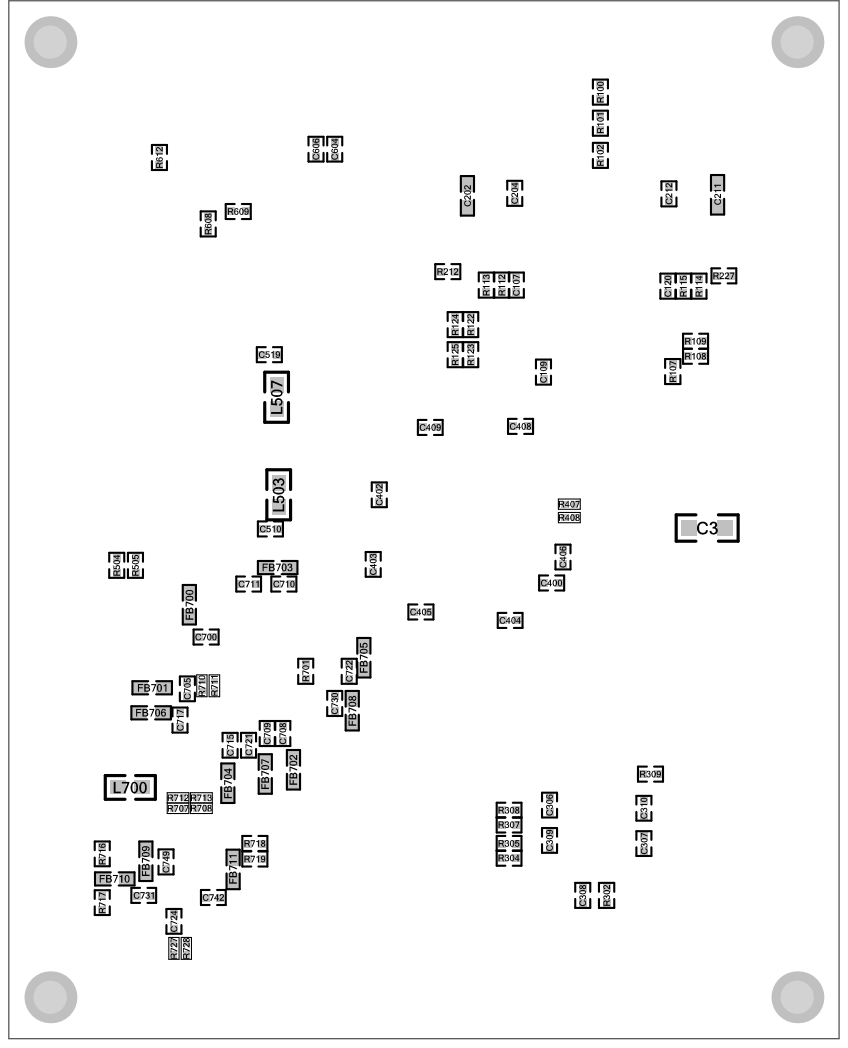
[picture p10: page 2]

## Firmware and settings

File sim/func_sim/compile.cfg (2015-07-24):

[file:.\..\..\hdl\spi_mux.vhd]
Enabled=1
[file:.\..\..\coregen\tx_mux.vhd]
Enabled=1
[file:.\..\..\coregen\rx_mux.vhd]
Enabled=1
[file:.\..\..\coregen\pll_main.vhd]
Enabled=1
[file:.\..\..\hdl\main.vhd]
Enabled=1
[View]
Entity=
Architecture=
TopLevelType=
[file:.\src\TestBench\main_TB.vhd]
Enabled=1
LIB=
[file:.\src\TestBench\main_TB_runtest.do]
Enabled=1
[file:.\..\..\coregen\mux_pll.vhd]
Enabled=1
[file:.\..\..\coregen\pll_mux.vhd]
Enabled=1
[file:.\..\..\hdl\spi_register.vhd]
Enabled=1

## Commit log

2013-10-11 initial commit added altium project and schematics
    [ADC.SchDoc, AtlysAFE.PrjPCB, DAC.SchDoc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]
2013-10-24 Added DAC
    [ADC.SchDoc, AtlysAFE.PrjPCB, DAC.SchDoc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]
2013-11-01 Added MachXO2 and FT2232 (as JTAG adapter) Added powersupplies
    [AtlysAFE.PrjPCB, DAC.SchDoc, FPGA.SchDoc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]
2013-11-14 analog input filters and configuration
    [ADC.SchDoc, AtlysAFE.PrjPCB, DAC.SchDoc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]
2013-11-21 Added ADC input stage
    [ADC.SchDoc, ADC_Input.SchDoc, AtlysAFE.PrjPCB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]
2013-12-05 added power calculations added clock generator
    [AtlysAFE.PrjPCB, Clock.SchDoc, Main.SchDoc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]
2013-12-12 Clock decoupling
    [Clock.SchDoc]
2014-01-09 added further clocking added MCX connectors for ADC, DAC and Clock
    [Clock.SchDoc, DAC.SchDoc, Main.SchDoc]
2014-01-14 added GPIOs unified LEDs FPGA wiring
    [ADC.SchDoc, Clock.SchDoc, DAC.SchDoc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]
2014-01-16 main sheet wiring clk control signals to fpga adc control signals to fpga
    [ADC.SchDoc, ADC_Input.SchDoc, Clock.SchDoc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]
2014-01-16 annotated components added signal names for differential adc signals renamed differential pairs to *_P/*_N 0 compile errors
    [ADC.SchDoc, ADC_Input.SchDoc, AtlysAFE.PrjPCB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]
2014-01-23 changed footprints of topside blocking Cs of ClockSynth Initial placement of parts on PCB
    [AtlysAFE.PcbDoc, Clock.SchDoc, FPGA.SchDoc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]
2014-01-23 placement of switching PSU corrected 2.5V Net (connecting to VHDCI connector)
    [AtlysAFE.PcbDoc, FPGA.SchDoc]
2014-01-30 switching PSU layout USB layout started
    [AtlysAFE.PcbDoc, USB.SchDoc]
2014-01-31 USB layout
    [AtlysAFE.PcbDoc]
2014-02-06 Started routing clock synth Updated Layer Stack
    [AtlysAFE.PcbDoc, Clock.SchDoc, FPGA.SchDoc]
2014-02-13 Changed 0603 footprints to "0603 SMALL OUTLINE" Placing of ADC componentes
    [ADC.SchDoc, ADC_Input.SchDoc, AtlysAFE.PcbDoc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]
2014-02-20 reduced board outline further submodule placement reorderd pins on VHDCI connector and FPGA for better routing
    [FPGA.SchDoc, Main.SchDoc]
2014-03-13 layout started
    [ADC.SchDoc, AtlysAFE.PrjPCB, Clock.SchDoc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]
2014-04-03 layout and differential impedance rules
    [ADC.SchDoc, ADC_Input.SchDoc, DAC.SchDoc]
2014-04-11 switched back to 6 layer (123um prepreg thickness)
2014-04-17 lvds lines routed
    [DAC.SchDoc, FPGA.SchDoc, Main.SchDoc]
2014-04-24 changed footprints (longer pads) changed DAC output network
    [ADC.SchDoc, Clock.SchDoc, DAC.SchDoc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]
2014-05-08 Updated footprint LFCSP32 (longer pads) changing width of differential lines (better match to 100R)
    [FPGA.SchDoc, Power.SchDoc]
2014-05-10 wider traces (100R matching)
2014-05-15 Added dual (quad) buffer for external clock
    [ADC.SchDoc, ADC_Input.SchDoc, AtlysAFE.PrjPCB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]
2014-05-15 placement of clock buffer added external power connector routing
    [Clock.SchDoc, Main.SchDoc, Power.SchDoc]
2014-05-16 fixed power net names
    [USB.SchDoc]
2014-05-18 routing of several FPGA control lines
    [Clock.SchDoc]
2014-05-28 routing complete
    [ADC.SchDoc, Clock.SchDoc, DAC.SchDoc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]
2014-05-28 updated 3D bodies minor corrections (planes) connector descriptions
    [Clock.SchDoc, Main.SchDoc]
2014-06-06 added thermal relief to planes and polygons changed via solder mask expansion according to ZVEI recommendation updated production files
    [Main.SchDoc]
2014-06-06 consolidated footprints and part comments
    [ADC.SchDoc, ADC_Input.SchDoc, AtlysAFE.PrjPCB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]
2014-06-18 Added SMD Pick and Place markers Added layer number to copper layers
    [AtlysAFE.PrjPCB, Main.SchDoc]
2014-06-18 added outputjob file generating production data
    [AtlysAFE.PrjPCB]
2014-07-02 added BOM in MS Excel and tab delimited text format
    [AtlysAFE BOM.xls]
2014-07-02 added assembly drawing
    [AtlysAFE.PrjPCB]
2014-07-11 corrected footprint of IC500 / IC502 regenerated production files and assembly PDF
2014-09-04 swapped IO4 with IO10 on VHDCI connector, so ADC bit clock is routed to FPGA clock input updated layout accordingly
    [Main.SchDoc]
2015-07-24 added spi register and simulation files
    [compile.cfg, library.cfg, projlib.cfg]
